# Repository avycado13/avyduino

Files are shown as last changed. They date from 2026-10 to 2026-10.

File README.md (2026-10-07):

# Avyduino

My take on the classic Arduino UNO. Powered by the same chips, but using a USB-C socket.
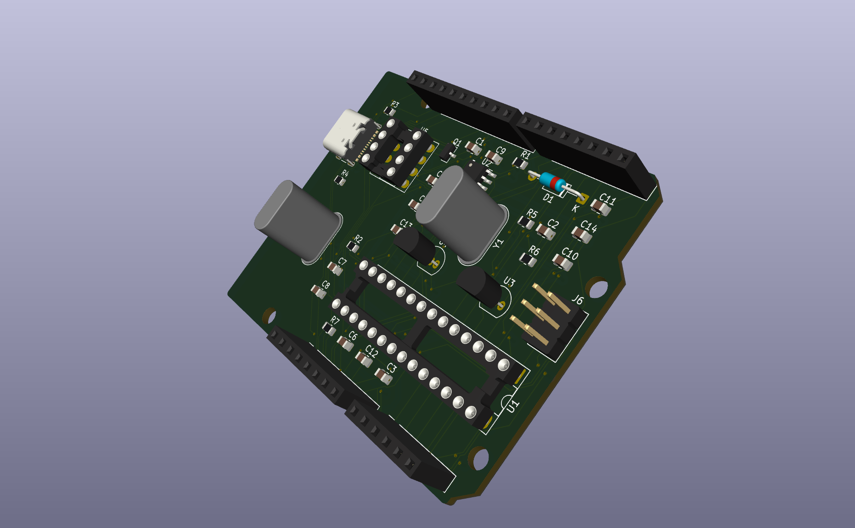
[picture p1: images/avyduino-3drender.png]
3D View

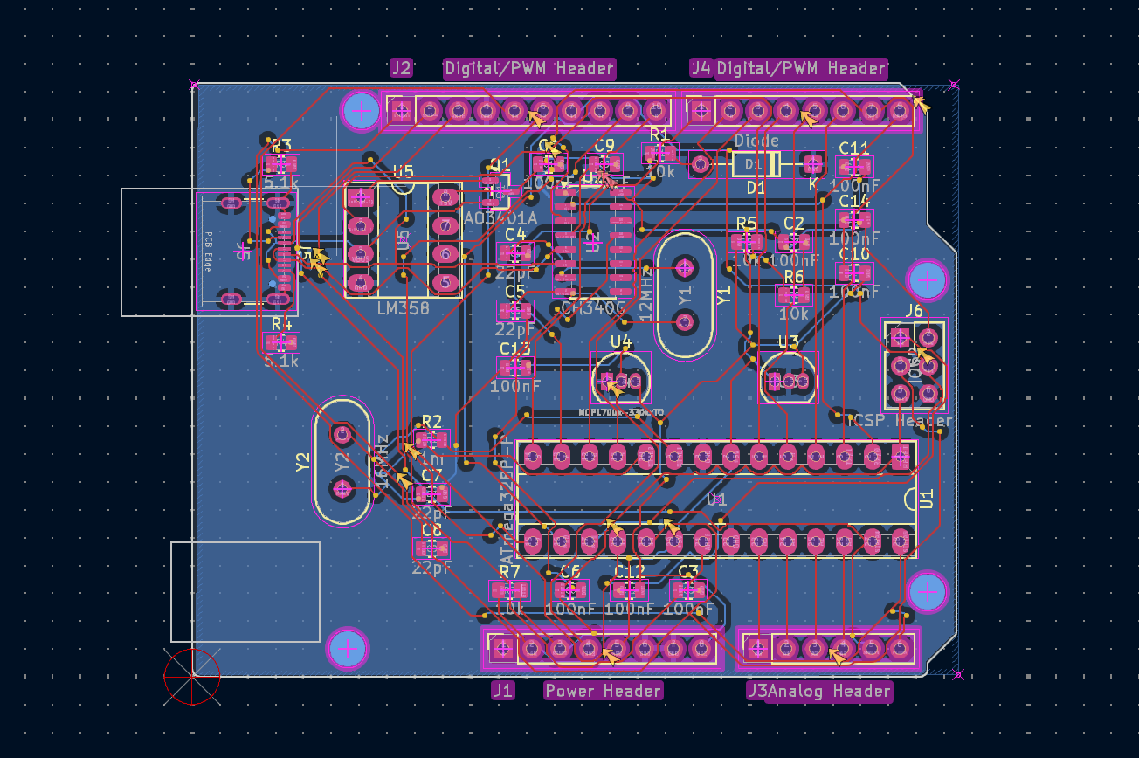
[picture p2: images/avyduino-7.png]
PCB


## Features
- USB-C
- Exact same pinout as classic Arduino UNO
- Power input switching
- Easy to solder components

## BOM
**FORGE REVIEWERS PLEASE ACTUALLY USE MY CSV**
I compiled 2 BOMs. One is from octopart and has parts sourced from multiple separate suppliers. [BOM here](ordering/bom.xlsx) and one entirely from LCSC. [BOM here](ordering/bom_lcsc_only.xlsx)

## Firmware
See [firmware/README.md](firmware/README.md) for the Uno Optiboot first-flash procedure and a USB serial bring-up sketch. The ATmega328P uses the standard Arduino Uno bootloader; the CH340G is a USB-to-UART bridge and does not need custom firmware.

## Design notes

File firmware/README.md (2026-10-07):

# Avyduino firmware

This board uses an **ATmega328P at 16 MHz** (Y2 in the schematic), a CH340G USB-to-UART bridge (its 12 MHz crystal is separate), and a 6-pin ICSP header. It is compatible with the **Arduino Uno** board definition. The bootloader is the official Uno **Optiboot** supplied by the `arduino:avr` core; no custom bootloader is needed. `firmware.ino` is a bring-up sketch: it echoes USB serial input at 115200 baud and toggles D13 every 500 ms. For a visible heartbeat, connect an external LED **with a current-limiting resistor** from D13 to GND; don't assume an onboard D13 LED.

## First-time programming (blank ATmega328P)

1. Install [Arduino CLI](https://arduino.github.io/arduino-cli/latest/installation/) and run `cd firmware && make core` (or install `arduino:avr` using the Arduino IDE Boards Manager).
2. Assemble and power the board. Connect a 5 V-compatible ISP programmer to the **ATmega328P's** 6-pin ICSP header: MISO, MOSI, SCK, RESET, 5V and GND. Check the physical header orientation against the PCB/schematic. Do not drive the target from two power supplies without checking their compatibility.
3. Run `make burn PROGRAMMER=usbasp` from `firmware/` (replace `usbasp` with your programmer's Arduino CLI ID). This writes Uno Optiboot and the Uno fuse settings. **Only do this if the ATmega's 16 MHz crystal and its load capacitors are populated**: the external-clock fuses can make ISP programming appear to stop working if the oscillator is absent. Bootloader burning is not done over the CH340G USB port.

## Upload and test

1. Connect USB-C and find the CH340G serial port using `arduino-cli board list` (e.g. `/dev/ttyUSB0`, `/dev/cu.wchusbserial*`, or `COM3`). On some systems the CH340 driver must be installed separately.
2. From `firmware/`, run `make upload PORT=/dev/ttyUSB0` (substitute your port). This builds for `arduino:avr:uno` and uploads at the Uno's bootloader baud rate. The programmer is **not** needed for this step. Alternatively open `firmware.ino` in Arduino IDE, select **Arduino Uno** and the CH340 serial port, and click Upload.
3. Open a serial monitor at **115200 baud**. Resetting or opening the port should print `Avyduino ready...`; text sent to it is echoed back. D13 changes state twice per second. If a terminal's local echo is enabled, characters may appear twice.

If USB upload fails, verify power, CH340 enumeration, that the bootloader was burned, and that the CH340 TX/RX and DTR-to-RESET connections are working. An ISP can also upload sketches directly, but doing so overwrites the bootloader; burn it again to restore USB uploads.

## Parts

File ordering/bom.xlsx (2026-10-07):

Original Part | Original Manufacturer | Matched Part Number | Part Match | Description | Quantity | Selected Offers | Selected Distributor | Selected Distributor SKU | Selected Offers (Distributor Link) | Stock | Unit Price, $ | Total Quantity | Total Price
CH340G |  |  | Not Found |  | 1
C0805C104K5RACTU |  | C0805C104K5RACTU | Exact | 50V 100nF X7R ±10% 0805 Multilayer Ceramic Capacitors MLCC - SMD/SMT ROHS | 10 | LCSC C75414 (https://octopart.com/opatz8j6/a1) | LCSC | C75414 (https://octopart.com/opatz8j6/a1) | https://octopart.com/opatz8j6/a1 | 4700 | 0.0415 | 10 | 0.415
C0805C220J5GACTU |  | C0805C220J5GACTU | Exact | Ceramic capacitor, 22 pF, 50 V (DC), ±5 %, SMD 0805 (2012), C0G, C0805C220J5GAC7800 | 4 | Newark C0805C220J5GACTU (https://octopart.com/opatz8j6/a1) | Newark | C0805C220J5GACTU (https://octopart.com/opatz8j6/a1) | https://octopart.com/opatz8j6/a1 | 815 | 0.171 | 4 | 0.684
1N4148 |  | 1N4148 | Exact | Rectifier Diode Single 2 EAR99 Diode Rectifier Diode 0.15A 0.004MUS 1V 150C | 1 | Mouser 512-1N4148 (https://octopart.com/opatz8j6/a1) | Mouser | 512-1N4148 (https://octopart.com/opatz8j6/a1) | https://octopart.com/opatz8j6/a1 | 1173802 | 0.1 | 1 | 0.1
SSW-108-01-T-S |  | SSW-108-01-T-S | Exact | PCB Receptacle, Board-to-Board, 2.54 mm, 1 Rows, 8 Contacts, Through Hole Mount, SSW Series | 1 | Mouser 200-SSW10801TS (https://octopart.com/opatz8j6/a1) | Mouser | 200-SSW10801TS (https://octopart.com/opatz8j6/a1) | https://octopart.com/opatz8j6/a1 | 1498 | 0.85 | 1 | 0.85
SSW-106-01-T-S |  | SSW-106-01-T-S | Exact | PCB Receptacle, Board-to-Board, 2.54 mm, 1 Rows, 6 Contacts, Through Hole Mount, SSW Series | 1 | Mouser 200-SSW10601TS (https://octopart.com/opatz8j6/a1) | Mouser | 200-SSW10601TS (https://octopart.com/opatz8j6/a1) | https://octopart.com/opatz8j6/a1 | 9012 | 0.58 | 1 | 0.58
SSW-108-01-T-S |  | SSW-108-01-T-S | Exact | PCB Receptacle, Board-to-Board, 2.54 mm, 1 Rows, 8 Contacts, Through Hole Mount, SSW Series | 1 | Mouser 200-SSW10801TS (https://octopart.com/opatz8j6/a1) | Mouser | 200-SSW10801TS (https://octopart.com/opatz8j6/a1) | https://octopart.com/opatz8j6/a1 | 1498 | 0.85 | 1 | 0.85
TSW-103-07-G-D |  | TSW-103-07-G-D | Exact | CONN HEADER VERT 6POS 2.54MM / Connector Header Through Hole 6 position 0.100" (2.54mm) | 1 | Mouser 200-TSW10307GD (https://octopart.com/opatz8j6/a1) | Mouser | 200-TSW10307GD (https://octopart.com/opatz8j6/a1) | https://octopart.com/opatz8j6/a1 | 7100 | 0.43 | 1 | 0.43
AO3401A |  | AO3401A | Exact | Transistor: P-MOSFET; unipolar; -30V; 4, 2A; 1, 4W; 85 mOhm; ; -55+150 st.C; SMD; SOT23 | 1 | LCSC C15127 (https://octopart.com/opatz8j6/a1) | LCSC | C15127 (https://octopart.com/opatz8j6/a1) | https://octopart.com/opatz8j6/a1 | 348335 | 0.1026 | 5 | 0.513
ERJ6ENF1002V |  | ERJ6ENF1002V | Exact | Res Thick Film 0805 10K Ohm 1% 1/8W ±100ppm/°C Molded SMD Punched Carrier T/R | 4 | Mouser 667-ERJ-6ENF1002V (https://octopart.com/opatz8j6/a1) | Mouser | 667-ERJ-6ENF1002V (https://octopart.com/opatz8j6/a1) | https://octopart.com/opatz8j6/a1 | 1016210 | 0.038 | 10 | 0.38
EE-SX953-W 1M |  | AC0805FR-071ML | Exact | SMD Chip Resistor, 1 MOhm, ¡À 1%, 125 mW, 0805 [2012 Metric], Thick Film, General Purpose | 1 | Mouser 603-AC0805FR-071ML (https://octopart.com/opatz8j6/a1) | Mouser | 603-AC0805FR-071ML (https://octopart.com/opatz8j6/a1) | https://octopart.com/opatz8j6/a1 | 10709 | 0.1 | 1 | 0.1
RC0805FR-075K1L |  | RC0805FR-075K1L | Exact | Res Thick Film 0805 5.1K Ohm 1% 0.125W(1/8W) ±100ppm/C Pad SMD T/R | 2 | Newark RC0805FR-075K1L (https://octopart.com/opatz8j6/a1) | Newark | RC0805FR-075K1L (https://octopart.com/opatz8j6/a1) | https://octopart.com/opatz8j6/a1 | 59224 | 0.101 | 2 | 0.202
LM2931AZ-5.0RAG |  | LM2931AZ-5.0RAG | Exact | LM2931 Series 100 mA 5 V Fixed Output Through Hole LDO Voltage Regulator - TO-92 | 1 | Mouser 863-LM2931AZ-5.0RAG (https://octopart.com/opatz8j6/a1) | Mouser | 863-LM2931AZ-5.0RAG (https://octopart.com/opatz8j6/a1) | https://octopart.com/opatz8j6/a1 | 1943 | 0.61 | 1 | 0.61
LM358S-13 |  | LM358S-13 | Exact | DIODES INC. LM358S-13 Operational Amplifier, Dual, 1 MHz, 2 Amplifier, 3V to 32V, SOIC, 8 Pins | 1 | Mouser 621-LM358S-13 (https://octopart.com/opatz8j6/a1) | Mouser | 621-LM358S-13 (https://octopart.com/opatz8j6/a1) | https://octopart.com/opatz8j6/a1 | 5902 | 0.23 | 1 | 0.23
ABLS2-12.000MHZ-D4Y-T |  | ABLS2-12.000MHZ-D4Y-T | Exact | Crystal 12MHz ±30ppm (Tol) ±30ppm (Stability) 18pF FUND 50Ohm 2-Pin HC-49/US SMD T/R | 1 | Newark ABLS2-12.000MHZ-D4Y-T (https://octopart.com/opatz8j6/a1) | Newark | ABLS2-12.000MHZ-D4Y-T (https://octopart.com/opatz8j6/a1) | https://octopart.com/opatz8j6/a1 | 43386 | 0.337 | 1 | 0.337
ABM8G-16.000MHZ-18-D2Y-T |  | ABM8G-16.000MHZ-18-D2Y-T | Exact | Crystal 16MHz ±20ppm (Tol) ±30ppm (Stability) 18pF FUND 80Ohm 4-Pin Ultra Mini-CSMD T/R | 1 | Newark ABM8G-16.000MHZ-18-D2Y-T (https://octopart.com/opatz8j6/a1) | Newark | ABM8G-16.000MHZ-18-D2Y-T (https://octopart.com/opatz8j6/a1) | https://octopart.com/opatz8j6/a1 | 1380 | 0.476 | 1 | 0.476
SSW-110-01-T-S |  | SSW-110-01-T-S | Exact | Samtec 2.54mmpitch10pSingle row female Board to Board, SSWseries, Straight, Through-hole | 1 | Mouser 200-SSW11001TS (https://octopart.com/opatz8j6/a1) | Mouser | 200-SSW11001TS (https://octopart.com/opatz8j6/a1) | https://octopart.com/opatz8j6/a1 | 6680 | 1.13 | 1 | 1.13
ATMEGA328P-PU |  | ATMEGA328P-PU | Exact | Microchip - ATMEGA328P-PU - Microcontroller Mcu, 8 Bit, Atmega, 20MHZ, DIP-28 | 1 | LCSC C33901 (https://octopart.com/opatz8j6/a1) | LCSC | C33901 (https://octopart.com/opatz8j6/a1) | https://octopart.com/opatz8j6/a1 | 703 | 2.62 | 1 | 2.62
SS-52400-002 |  | SS-52400-002 | Exact | Conn USB Type C RCP 14 POS 0.4mm/0.8mm Solder RA Thru-Hole 14 Terminal 1 Port T/R | 1 | LCSC C3197989 (https://octopart.com/opatz8j6/a1) | LCSC | C3197989 (https://octopart.com/opatz8j6/a1) | https://octopart.com/opatz8j6/a1 | 126 | 4.74 | 1 | 4.74

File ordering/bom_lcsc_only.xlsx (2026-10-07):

bom.xlsx |  |  |  |  |  |  |  |  |  | LCSC BOM Quotation
 |  |  |  |  |  |  |  |  |  | BOM Date Created：07/10/26 10:29:34 |  |  |  | BOM Export Date: 07/10/26 10:30:51 |  |  |  | The matching result is a real-time query result, availability and prices may fluctuate. Backorder items are estimated prices for your reference, please submit "Create Quote" to get the real price. All information is provided "as is" and is subject to change without notice. Any use made of the information provided is without recourse to LCSC and at the user's risk.
 |  |  |  |  |  |  |  |  |  | EST TOTAL :$17.35 |  |  |  | Website：https://www.lcsc.com/bom | https://www.lcsc.com/bom | https://www.lcsc.com/bom | https://www.lcsc.com/bom
Uploaded data |  |  |  |  |  |  |  |  |  | LCSC Matching Results
LCSC# | Mfr. | Mrf# | Description | Package | Value | Customer Part Number | Quantity | Target Price(USD) | Target Lead Time(Business Days) | Mrf# | Mfr. | Order Qty. | Unit Price(USD) | Ext.Price(USD) | LCSC# | Package | Min | Mult | SPQ | Availability | Stock Status | Customer Notes | Description | Matched status | Product Link
 |  |  |  |  |  |  | 1 |  |  | -(The data has been deleted.) | - | - | - | - | - | - | - | - | - | - | - | - | - | - | https://uat.lcsc.com/product-detail/schottky-barrier-diodes-sbd_lge-10mq040n_C688893.html
 |  | C0805C104K5RACTU | 50V 100nF X7R ±10% 0805 Multilayer Ceramic Capacitors MLCC - SMD/SMT ROHS |  |  | - | 10 |  |  | C0805C104K5RACTU | KEMET | 10 | 0.0310 | 0.31 | C3018562 | - | 10 | 10 | 4000 | 4270 | In Stock |  | 100nF ±10% 50V Ceramic Capacitor X7R 0805 | Exact Matches
 |  | C0805C220J5GACTU | Ceramic capacitor, 22 pF, 50 V (DC), ±5 %, SMD 0805 (2012), C0G, C0805C220J5GAC7800 |  |  | - | 4 |  |  | C0805C220J5GACTU | KEMET | 50 | 0.0135 | 0.68 | C22401914 | - | 50 | 50 | 4000 | 2400 | In Stock |  | 22pF C0G ±5% 50V 0805 Ceramic Capacitors RoHS | Exact Matches
 |  | 1N4148 | Rectifier Diode Single 2 EAR99 Diode Rectifier Diode 0.15A 0.004MUS 1V 150C |  |  | - | 1 |  |  | 1N4148 | Changzhou Starsea Elec | 50 | 0.0084 | 0.42 | C85057 | - | 50 | 50 | 5000 | 29200 | In Stock |  | Diode 100V 150mA Through Hole DO-35 | Exact Matches
 |  | SSW-108-01-T-S | PCB Receptacle, Board-to-Board, 2.54 mm, 1 Rows, 8 Contacts, Through Hole Mount, SSW Series |  |  | - | 1 |  |  | SSW-108-01-T-S | Samtec | 1 | 0.8600 | 0.86 | C6236331 | Through Hole,P=2.54mm | 1 | 1 | 7 | 3 | In Stock |  | Female Header 8 Position 2.54mm Pitch Single Row Through Hole -55℃~+105℃ | Exact Matches | https://www.lcsc.com/product-detail/C6236331.html
 |  | SSW-106-01-T-S | PCB Receptacle, Board-to-Board, 2.54 mm, 1 Rows, 6 Contacts, Through Hole Mount, SSW Series |  |  | - | 1 |  |  | SSW-106-01-T-S | Samtec | 1 | 1.2470 | 1.25 | C3323824 | - | 1 | 1 | 7 | 0 | Backordered |  | Female Header 6 Position 2.54mm Pitch Single Row Through Hole -55℃~+105℃ | Exact Matches
 |  | SSW-108-01-T-S | PCB Receptacle, Board-to-Board, 2.54 mm, 1 Rows, 8 Contacts, Through Hole Mount, SSW Series |  |  | - | 1 |  |  | SSW-108-01-T-S | Samtec | 1 | 0.8600 | 0.86 | C6236331 | Through Hole,P=2.54mm | 1 | 1 | 7 | 3 | In Stock |  | Female Header 8 Position 2.54mm Pitch Single Row Through Hole -55℃~+105℃ | Exact Matches | https://www.lcsc.com/product-detail/C6236331.html
 |  | TSW-103-07-G-D | CONN HEADER VERT 6POS 2.54MM / Connector Header Through Hole 6 position 0.100" (2.54mm) |  |  | - | 1 |  |  | TSW-103-07-G-D | Samtec | 1 | 0.6589 | 0.66 | C6339671 | - | 1 | 1 | 2000 | 34 | In Stock |  | Pin Header 6 Position 2.54mm Pitch Dual Row Through Hole -55℃~+125℃ | Exact Matches
 |  | AO3401A | Transistor: P-MOSFET; unipolar; -30V; 4, 2A; 1, 4W; 85 mOhm; ; -55+150 st.C; SMD; SOT23 |  |  | - | 1 |  |  | AO3401A | TECH PUBLIC | 20 | 0.0248 | 0.50 | C5122001 | - | 20 | 20 | 3000 | 50240 | In Stock |  | 30V 4.2A 1.2W Surface Mount SOT-23 | Exact Matches
 |  | ERJ6ENF1002V | Res Thick Film 0805 10K Ohm 1% 1/8W ±100ppm/°C Molded SMD Punched Carrier T/R |  |  | - | 4 |  |  | ERJ6ENF1002V | PANASONIC | 50 | 0.0052 | 0.26 | C169253 | - | 50 | 50 | 5000 | 36750 | In Stock |  | 125mW 10kΩ Thick Film Resistor ±100ppm/℃ ±1% 0805 Chip Resistor - Surface Mount RoHS | Exact Matches
 |  | AC0805FR-071ML | SMD Chip Resistor, 1 MOhm, ¡À 1%, 125 mW, 0805 [2012 Metric], Thick Film, General Purpose |  |  | - | 1 |  |  | AC0805FR-071ML | YAGEO | 100 | 0.0032 | 0.32 | C228604 | - | 100 | 100 | 5000 | 247300 | In Stock |  | 125mW 1MΩ 150V Thick Film Resistor ±100ppm/℃ ±1% 0805 Chip Resistor - Surface Mount RoHS | Exact Matches
 |  | RC0805FR-075K1L | Res Thick Film 0805 5.1K Ohm 1% 0.125W(1/8W) ±100ppm/C Pad SMD T/R |  |  | - | 2 |  |  | RC0805FR-075K1L | YAGEO | 100 | 0.0016 | 0.16 | C84375 | - | 100 | 100 | 5000 | 790200 | In Stock |  | 5.1kΩ 125mW 150V Thick Film Resistor ±100ppm/℃ ±1% 0805 Chip Resistor - Surface Mount RoHS | Exact Matches
 |  | LM2931AZ-5.0RAG | LM2931 Series 100 mA 5 V Fixed Output Through Hole LDO Voltage Regulator - TO-92 |  |  | - | 1 |  |  | LM2931AZ-5.0RAG | onsemi | 1 | 0.3193 | 0.32 | C415867 | - | 1 | 1 | 2000 | 0 | Backordered |  | Linear Voltage Regulator IC Positive Fixed 1 Output 100mA TO-92 | Exact Matches
 |  | LM358S-13 | DIODES INC. LM358S-13 Operational Amplifier, Dual, 1 MHz, 2 Amplifier, 3V to 32V, SOIC, 8 Pins |  |  | - | 1 |  |  | LM358S-13 | DIODES | 5 | 0.1518 | 0.76 | C2058968 | SOP-8 | 5 | 5 | 2500 | 850 | In Stock |  | 60mA 2 2mV 85dB 45nA 1mA 1MHz SOP-8 Instrumentation, Op Amps, Buffer Amps RoHS | Exact Matches | https://www.lcsc.com/product-detail/C2058968.html
 |  | ABLS2-12.000MHZ-D4Y-T | Crystal 12MHz ±30ppm (Tol) ±30ppm (Stability) 18pF FUND 50Ohm 2-Pin HC-49/US SMD T/R |  |  | - | 1 |  |  | ABLS2-12.000MHZ-D4Y-T | ABRACON | 5 | 0.2564 | 1.28 | C1985239 | - | 5 | 5 | 1000 | 1260 | In Stock |  | Crystal 12MHz ±30ppm 18pF 50Ω HC-49S-SMD | Exact Matches
 |  | ABM8G-16.000MHZ-18-D2Y-T | Crystal 16MHz ±20ppm (Tol) ±30ppm (Stability) 18pF FUND 80Ohm 4-Pin Ultra Mini-CSMD T/R |  |  | - | 1 |  |  | ABM8G-16.000MHZ-18-D2Y-T | ABRACON | 1 | 0.3804 | 0.38 | C1985423 | - | 1 | 1 | 1000 | 710 | In Stock |  | Crystal 16MHz ±20ppm 18pF 80Ω SMD3225-4P | Exact Matches
 |  | SSW-110-01-T-S | Samtec 2.54mmpitch10pSingle row female Board to Board, SSWseries, Straight, Through-hole |  |  | - | 1 |  |  | SSW-110-01-T-S | Samtec | 1 | 1.3004 | 1.30 | C6825788 | Through Hole,P=2.54mm | 1 | 1 | 7 | 9 | In Stock |  | Female Header 10 Position 2.54mm Pitch Single Row Through Hole -55℃~+105℃ | Exact Matches | https://www.lcsc.com/product-detail/C6825788.html
 |  | ATMEGA328P-PU | Microchip - ATMEGA328P-PU - Microcontroller Mcu, 8 Bit, Atmega, 20MHZ, DIP-28 |  |  | - | 1 |  |  | ATMEGA328P-PU | MICROCHIP | 1 | 2.3274 | 2.33 | C33901 | - | 1 | 1 | 14 | 691 | In Stock |  | AVR 8 Bit 20MHz DIP-28-300mil Microcontrollers RoHS | Exact Matches
 |  | SS-52400-002 | Conn USB Type C RCP 14 POS 0.4mm/0.8mm Solder RA Thru-Hole 14 Terminal 1 Port T/R |  |  | - | 1 |  |  | SS-52400-002 | Bel Fuse | 1 | 4.1276 | 4.13 | C3197989 | - | 1 | 1 | 700 | 124 | In Stock |  | USB 3.2 1 24P -40℃~+105℃ Right Angle Through Hole USB, DVI, HDMI Connector Assemblies RoHS | Exact Matches
 |  |  |  |  |  |  | 1 |  |  | CH340G | WCH | 1 | 0.5715 | 0.57 | C14267 | SOP-16 | 1 | 1 | 50 | 27331 | In Stock |  | USB to UART 2Mbps USB 2.0 SOP-16 Interface Controllers | Exact Matches | https://www.lcsc.com/product-detail/C14267.html

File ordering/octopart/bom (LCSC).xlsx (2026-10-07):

Designator | Footprint | Quantity | Value | LCSC Part # | Original Part | Original Manufacturer | Matched Part Number | Part Match | Description | Quantity | Selected Offers | Selected Distributor | Selected Distributor SKU | Selected Offers (Distributor Link) | Stock | Unit Price, $ | Total Quantity | Total Price
C1, C2, C3, C6, C9, C10, C11, C12, C13, C14 | 0805 | 10 | 100nF | C0805C104K5RACTU | C0805C104K5RACTU |  | C0805C104K5RACTU | Exact | 50V 100nF X7R ±10% 0805 Multilayer Ceramic Capacitors MLCC - SMD/SMT ROHS | 10 | LCSC C75414 (https://octopart.com/opatz8j6/a1) | LCSC | C75414 (https://octopart.com/opatz8j6/a1) | https://octopart.com/opatz8j6/a1 | 4700 | 0.0415 | 10 | 0.415
Q1 | SOT-23 | 1 | AO3401A | AO3401A | AO3401A |  | AO3401A | Exact | Transistor: P-MOSFET; unipolar; -30V; 4, 2A; 1, 4W; 85 mOhm; ; -55+150 st.C; SMD; SOT23 | 1 | LCSC C15127 (https://octopart.com/opatz8j6/a1) | LCSC | C15127 (https://octopart.com/opatz8j6/a1) | https://octopart.com/opatz8j6/a1 | 348335 | 0.1026 | 5 | 0.513
U1 | DIP-28_W7.62mm_Socket_LongPads | 1 | ATmega328P-P | ATMEGA328P-PU | ATMEGA328P-PU |  | ATMEGA328P-PU | Exact | Microchip - ATMEGA328P-PU - Microcontroller Mcu, 8 Bit, Atmega, 20MHZ, DIP-28 | 1 | LCSC C33901 (https://octopart.com/opatz8j6/a1) | LCSC | C33901 (https://octopart.com/opatz8j6/a1) | https://octopart.com/opatz8j6/a1 | 703 | 2.62 | 1 | 2.62
J5 | USB_C_Receptacle_GCT_USB4105-xx-A_16P_TopMnt_Horizontal | 1 | USB_C_Receptacle_USB2.0_14P | SS-52400-002 | SS-52400-002 |  | SS-52400-002 | Exact | Conn USB Type C RCP 14 POS 0.4mm/0.8mm Solder RA Thru-Hole 14 Terminal 1 Port T/R | 1 | LCSC C3197989 (https://octopart.com/opatz8j6/a1) | LCSC | C3197989 (https://octopart.com/opatz8j6/a1) | https://octopart.com/opatz8j6/a1 | 126 | 4.74 | 1 | 4.74

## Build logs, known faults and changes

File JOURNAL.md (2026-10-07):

---
title: "avyduino"
github: "avycado13/avyduino"
description: "an arduino but my way"
created_at: "2026-10-04"
---

# Oct 5: Started Project and Made Schematic
I had the idea to make my own Arduino UNO based on the same chips but hand solderable and cooler!
I used an ATmega328p for the microcontroller and a CH340G to convert USB to UART. Making the power systems was a bit hard because I had to replicate Arduino's system of using an Op-amp and a MOSFET to decide between using the VBUS from USB and the VIN from the pins. I used KiCad's Arduino UNO template which already had the pin headers set up in the right order. For USB, I went with a USB-C port because its more modern and easier to find a cable for then that obscure USB-B that Arduino's usually come with. A big help in this was [Kai's build your own devboard guide](https://kaipereira.com/journal/build-a-devboard) and online Arduino schematics.

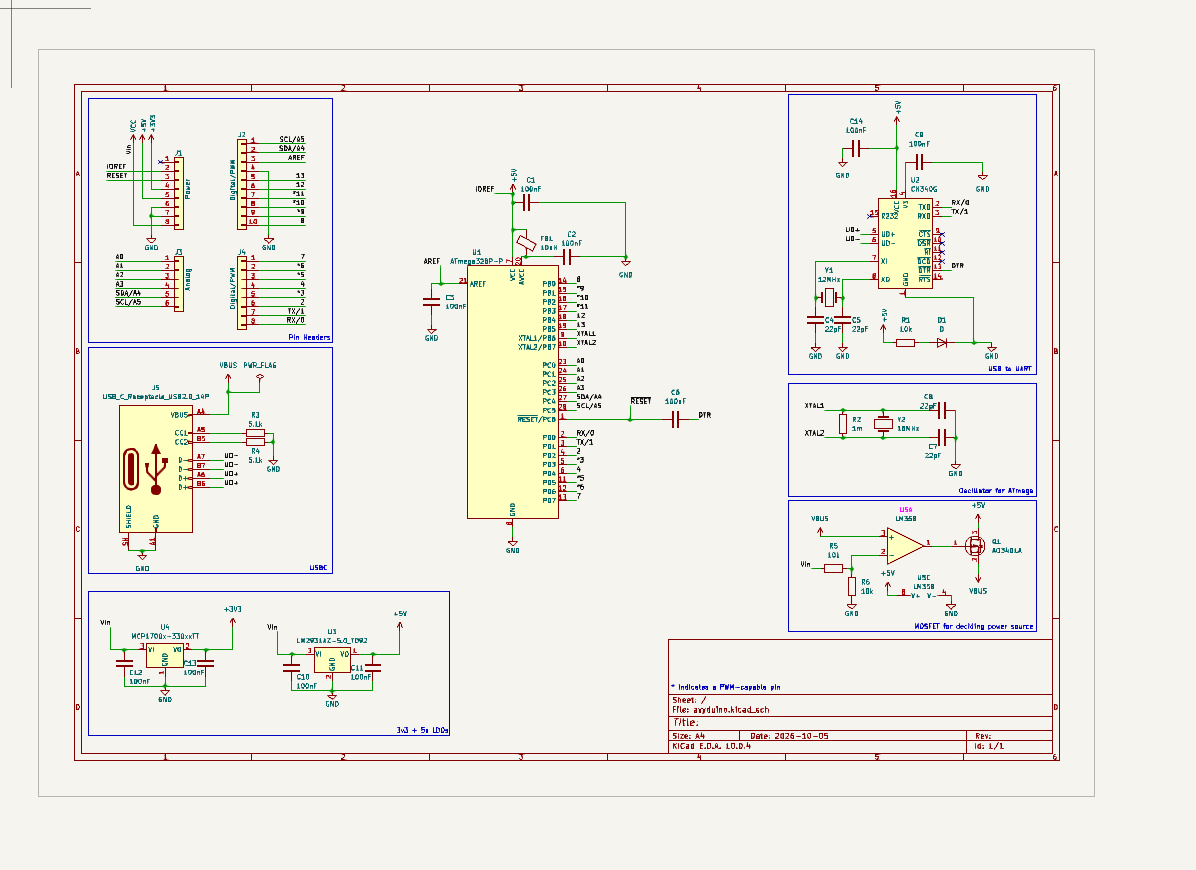
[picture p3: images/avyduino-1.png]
Final Schematic

**Total Time Spent: 3 Hours**

# Oct 5: Laid out PCB
I laid out my PCB. The KiCad template already had the shape I needed in it so I didn't need to try drawing it. I tried laying things out to be close to where they need to connect, especially my decoupling capacitors because on past projects I screwed it up and forgot that they should go closer to the place they are connected to.

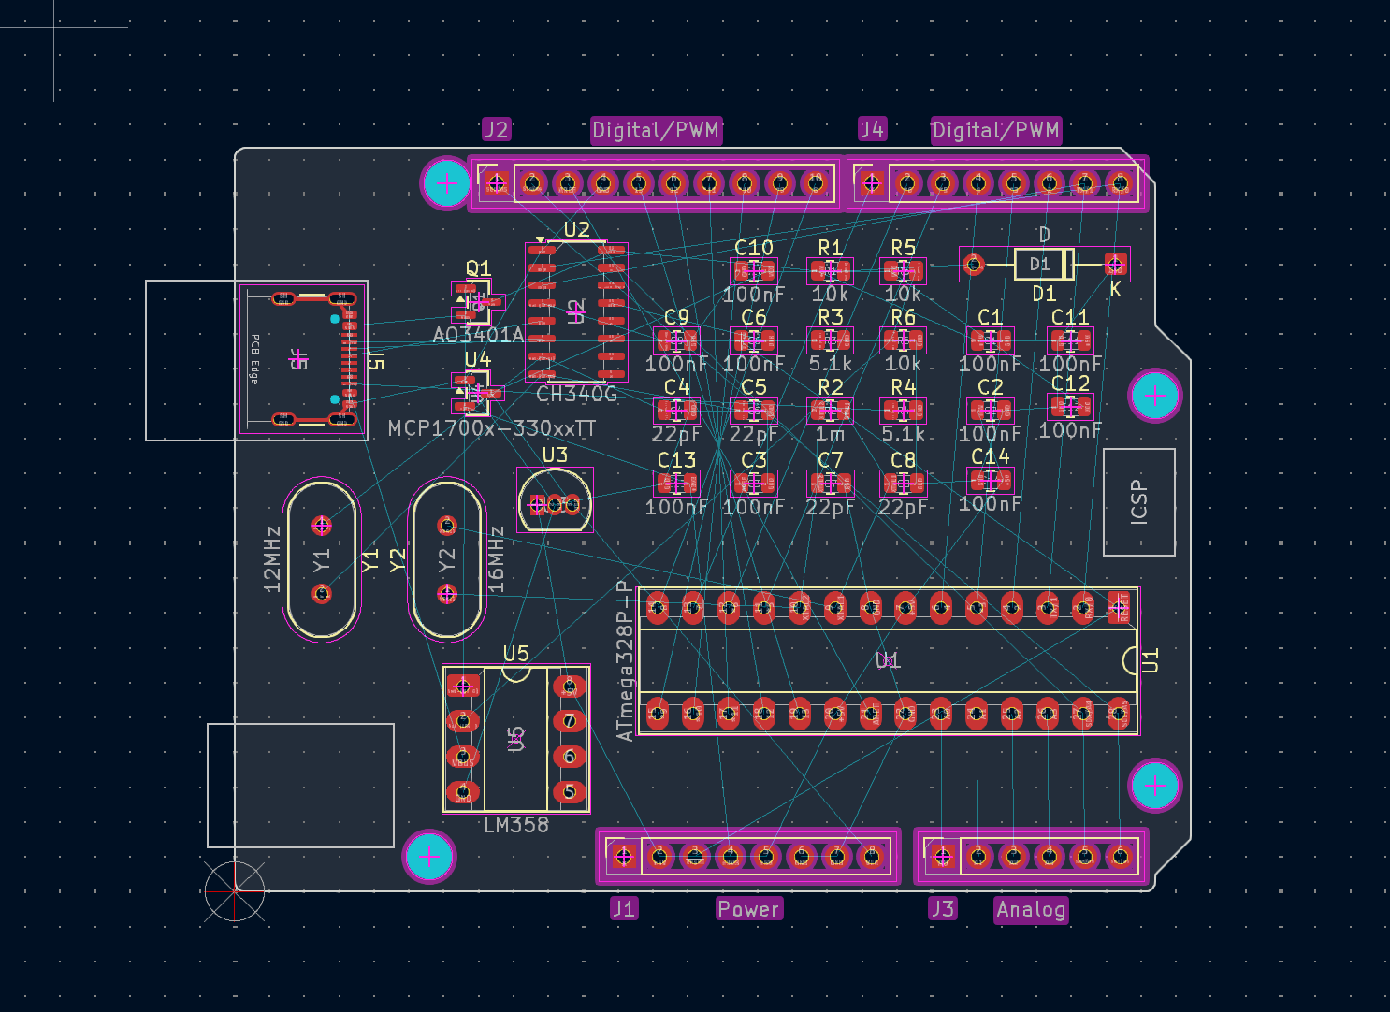
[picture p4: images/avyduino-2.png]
Completed Layout

**Total Time Spent: 2 Hours**

# Oct 5: Routed PCB
I routed my PCB through the night with one GND plane and one plane for VCC. I routed it with standard size traces and kinda went overboard on the vias.

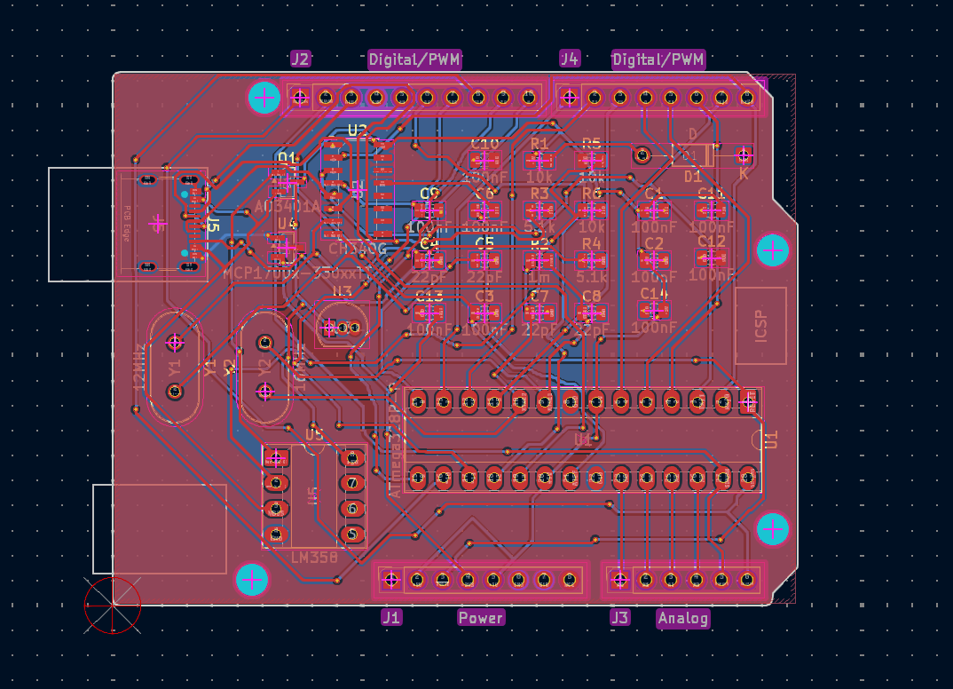
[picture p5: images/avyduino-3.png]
Completed PCB with Layout

**Total Time Spent: 1.5 Hour**

# Oct 6: Add ICSP Header
I forgot to add an ICSP header for flashing it initially. So I added one to my schematic. I was a bit confused by the fact that it uses an SPI bus that also doubles as PWM pins but now it makes sense, but its still weird that it uses pins that could be occupied. it apparently just pulses really fast during flashing.

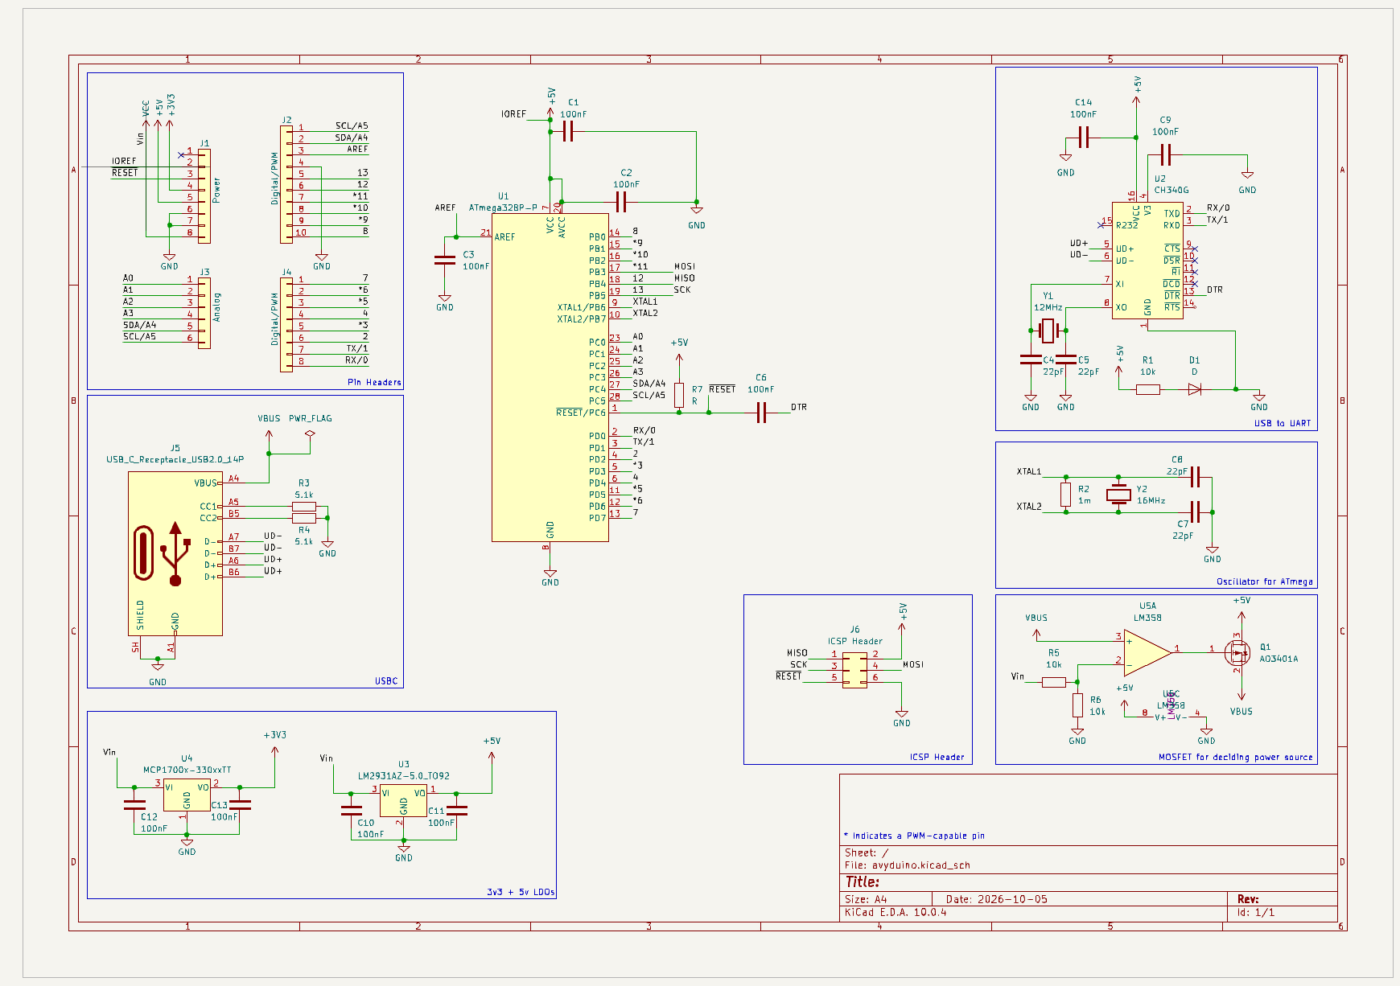
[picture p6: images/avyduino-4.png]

**Total Time Spent: 1 Hour**

# Oct 6: Add ICSP Header to PCB
I added the ICSP header to the PCB and routed it. The DRC and ERC both pass, so I think I am good. Next, I just need to source the parts and write my README.

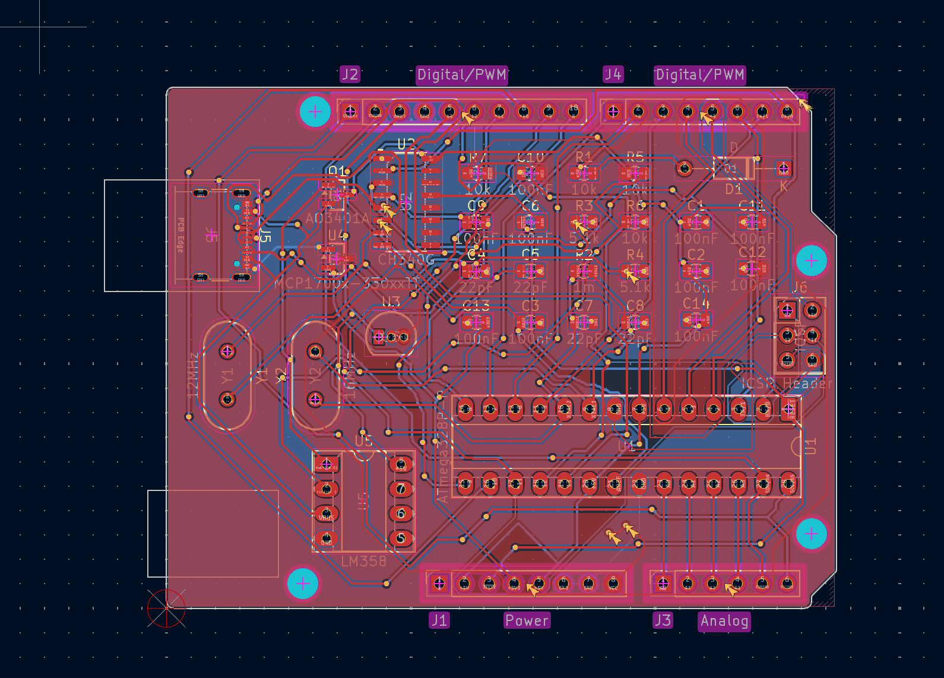
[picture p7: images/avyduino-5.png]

**Total Time Spent: 0.5 Hour**

# Oct 6: Redo Layout of PCB
I had started to put part numbers on things when I realized that my layout wasn't that great and I could make it better and I also wanted to switch the footprint of some things to be easier to solder. I redid the layout and updated some names and footprints.

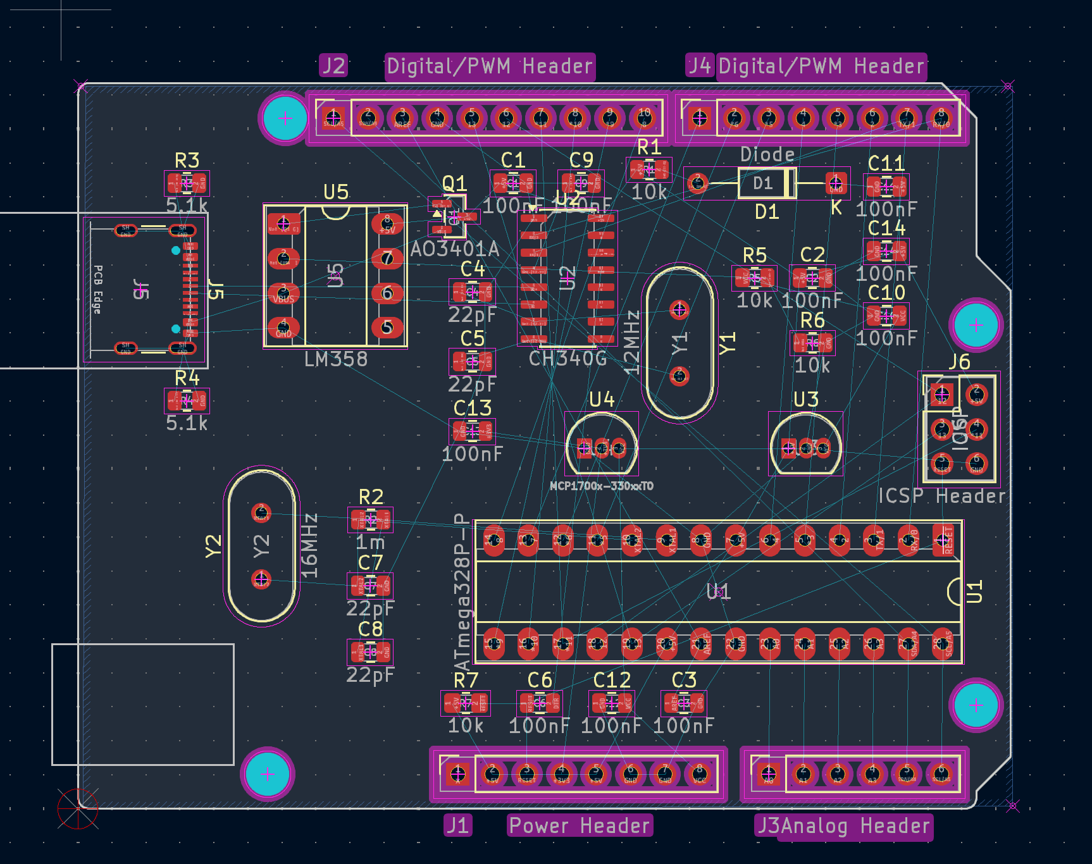
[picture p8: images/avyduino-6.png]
New PCB Layout

**Total Time Spent: 1 Hour**

# Oct 6: Route PCB
I rerouted the PCB with the new layout. For this one, I got rid of the Front VCC plane and only used a ground plane on the back layer. I forgot to commit this journal log because I had to do something so ya.
Routed PCB with new layout
**Total Time Spent: 1 Hour**

# Oct 6: Make BOMs
I made the BOMs in octopart and exported the production files. I also made one BOM that uses only LCSC parts.

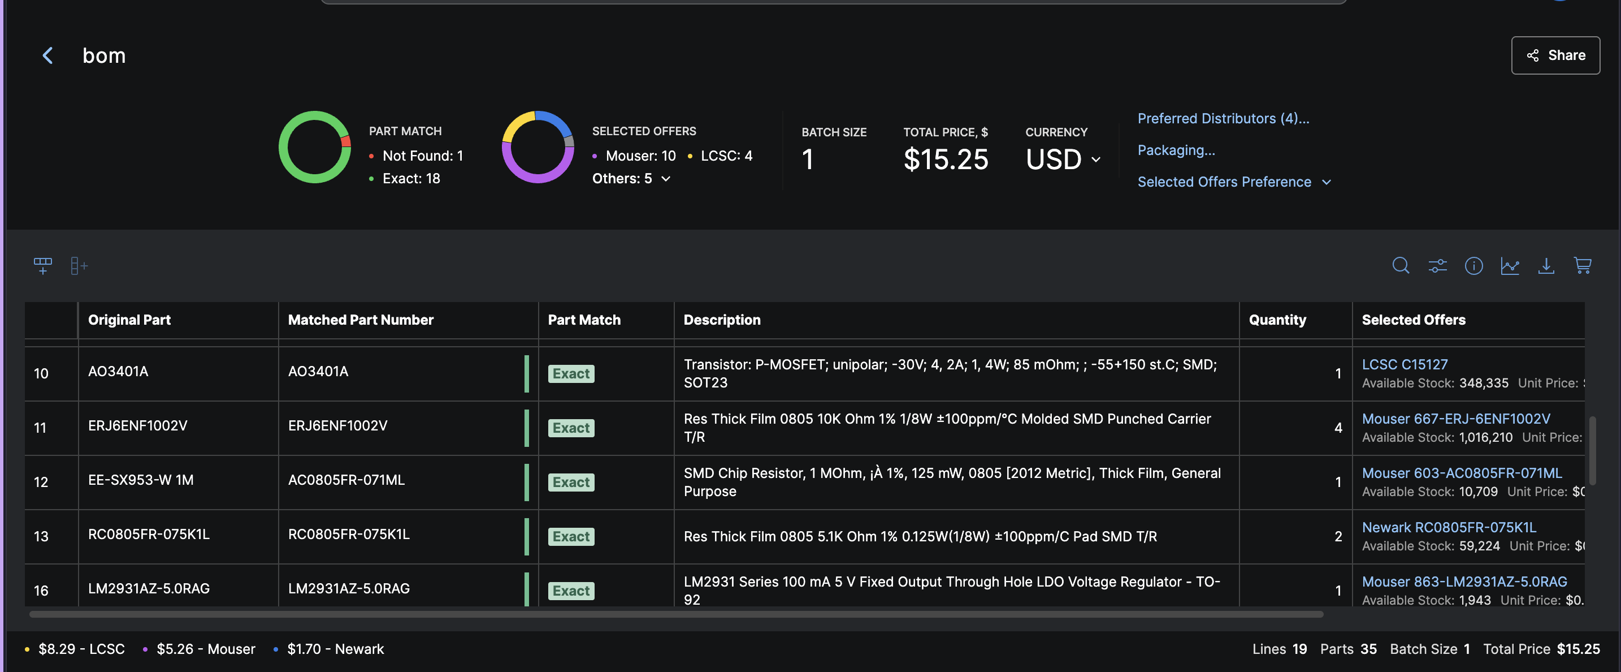
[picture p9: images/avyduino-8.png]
Octopart

**Total Time Spent: 1.5 Hour**

# Oct 7: Add firmware
I added a basic sketch to flash an LED on pin D13 every 0.5 seconds and a Makefile to flash the arduino. there is one command to burn it to the bootloader initially and one for normal flashing. Both just use arduino-cli, so it should work in Arduino IDE. I don't know what image to put, so I am putting the KiCad 3d render.

3D View
**Total Time Spent: 1.5 Hour**

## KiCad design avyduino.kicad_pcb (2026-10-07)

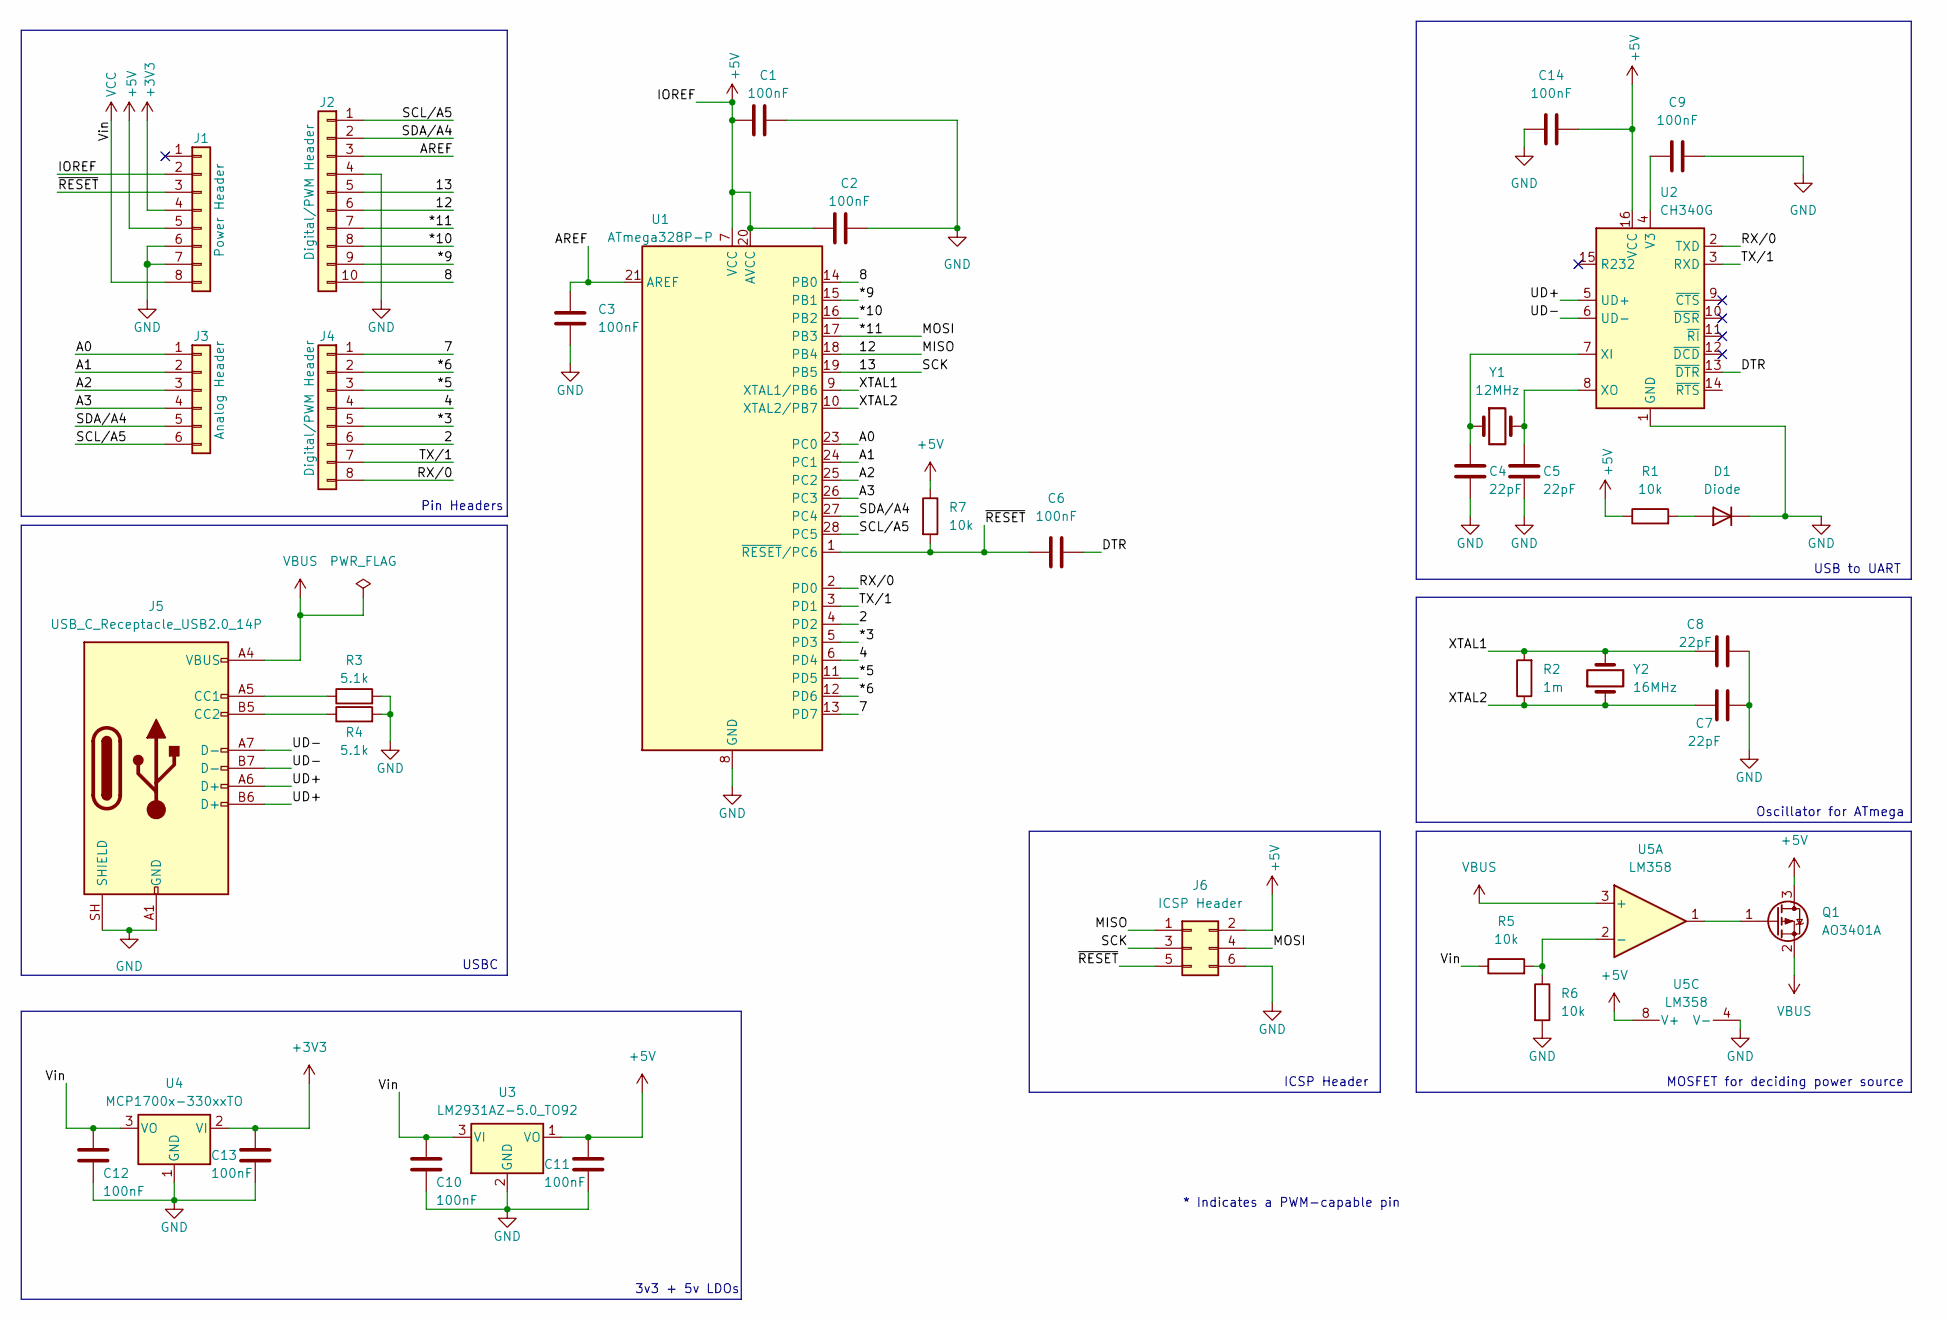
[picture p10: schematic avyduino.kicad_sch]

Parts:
C1, C2, C3, C6, C9, C10, C11, C12, C13, C14: 100nF; C_0805_2012Metric; MPN C0805C104K5RACTU
C4, C5, C7, C8: 22pF; C_0805_2012Metric; MPN C0805C220J5GACTU
D1: Diode; D_DO-35_SOD27_P10.16mm_Horizontal; MPN 1N4148
J1: Power Header; PinSocket_1x08_P2.54mm_Vertical; MPN SSW-108-01-T-S
J2: Digital/PWM Header; PinSocket_1x10_P2.54mm_Vertical; MPN SSW-110-01-T-S
J3: Analog Header; PinSocket_1x06_P2.54mm_Vertical; MPN SSW-106-01-T-S
J4: Digital/PWM Header; PinSocket_1x08_P2.54mm_Vertical; MPN SSW-108-01-T-S
J5: USB_C_Receptacle_USB2.0_14P; USB_C_Receptacle_GCT_USB4105-xx-A_16P_TopMnt_Horizontal; MPN SS-52400-002
J6: ICSP Header; PinHeader_2x03_P2.54mm_Vertical; MPN TSW-103-07-G-D
Q1: AO3401A; SOT-23; MPN AO3401A
R1, R5, R6: 10k; R_0805_2012Metric; MPN ERJ6ENF1002V
R2: 1m; R_0805_2012Metric; MPN AC0805FR-071ML
R3, R4: 5.1k; R_0805_2012Metric; MPN RC0805FR-075K1L
R7: 10k; R_0805_2012Metric_Pad1.20x1.40mm_HandSolder; MPN ERJ6ENF1002V
U1: ATmega328P-P; DIP-28_W7.62mm_Socket_LongPads; MPN ATMEGA328P-PU
U2: CH340G; SOIC-16_3.9x9.9mm_P1.27mm; MPN CH340G
U3: LM2931AZ-5.0_TO92; TO-92_Inline; MPN LM2931AZ-5.0RAG
U4: MCP1700x-330xxTO; TO-92_Inline; MPN MCP1700x-33002E/TO
U5: LM358; DIP-8_W7.62mm_Socket_LongPads; MPN LM358S-13
Y1: 12MHz; Crystal_HC49-U_Vertical; MPN ABLS2-12.000MHZ-D4Y-T
Y2: 16MHz; Crystal_HC49-U_Vertical; MPN ABM8G-16.000MHZ-18-D2Y-T

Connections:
+3V3: C13.2, J1.4, U4.2 (VI)
+5V: C1.1, C2.1, C11.2, C14.2, J1.2, J1.5, J6.2, Q1.3 (D), R1.1, R7.1, U1.7 (VCC), U1.20 (AVCC), U2.16 (VCC), U3.1 (VO), U5.8 (V+)
/2: J4.6, U1.4 (PD2)
/4: J4.4, U1.6 (PD4)
/7: J4.1, U1.13 (PD7)
/8: J2.10, U1.14 (PB0)
/12: J2.6, J6.1, U1.18 (PB4)
/13: J2.5, J6.3, U1.19 (PB5)
/*3: J4.5, U1.5 (PD3)
/*5: J4.3, U1.11 (PD5)
/*6: J4.2, U1.12 (PD6)
/*9: J2.9, U1.15 (PB1)
/*10: J2.8, U1.16 (PB2)
/*11: J2.7, J6.4, U1.17 (PB3)
/A0: J3.1, U1.23 (PC0)
/A1: J3.2, U1.24 (PC1)
/A2: J3.3, U1.25 (PC2)
/A3: J3.4, U1.26 (PC3)
/AREF: C3.1, J2.3, U1.21 (AREF)
/DTR: C6.2, U2.13 (~DTR)
/RX/0: J4.8, U1.2 (PD0), U2.2 (TXD)
/SCL/A5: J2.1, J3.6, U1.28 (PC5)
/SDA/A4: J2.2, J3.5, U1.27 (PC4)
/TX/1: J4.7, U1.3 (PD1), U2.3 (RXD)
/UD+: J5.A6 (D+), J5.B6 (D+), U2.5 (UD+)
/UD-: J5.A7 (D-), J5.B7 (D-), U2.6 (UD-)
/XTAL1: C8.1, R2.2, U1.9 (XTAL1/PB6), Y2.2
/XTAL2: C7.1, R2.1, U1.10 (XTAL2/PB7), Y2.1
/~RESET: C6.1, J1.3, J6.5, R7.2, U1.1 (~RESET/PC6)
GND: C1.2, C2.2, C3.2, C4.2, C5.2, C7.2, C8.2, C9.2, C10.1, C11.1, C12.1, C13.1, C14.1, D1.1 (K), J1.6, J1.7, J2.4, J5.A1 (GND), J5.A12 (GND), J5.B1 (GND), J5.B12 (GND), J5.SH (SHIELD), J6.6, R3.2, R4.2, R6.2, U1.8 (GND), U1.22 (GND), U2.1 (GND), U3.2 (GND), U4.1 (GND), U5.4 (V-)
unnamed: D1.2 (A), R1.2
unnamed: J5.A5 (CC1), R3.1
unnamed: J5.B5 (CC2), R4.1
unnamed: Q1.1 (G), U5.1
unnamed: C9.1, U2.4 (V3)
unnamed: C4.1, U2.7 (XI), Y1.1
unnamed: C5.1, U2.8 (XO), Y1.2
unnamed: R5.2, R6.1, U5.2 (-)
VBUS: J5.A4 (VBUS), J5.A9 (VBUS), J5.B4 (VBUS), J5.B9 (VBUS), Q1.2 (S), U5.3 (+)
VCC: C10.2, C12.2, J1.8, R5.1, U3.3 (VI), U4.3 (VO)

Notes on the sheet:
3v3 + 5v LDOs
ICSP Header
USB to UART
Pin Headers
MOSFET for deciding power source
* Indicates a PWM-capable pin
Oscillator for ATmega
USBC

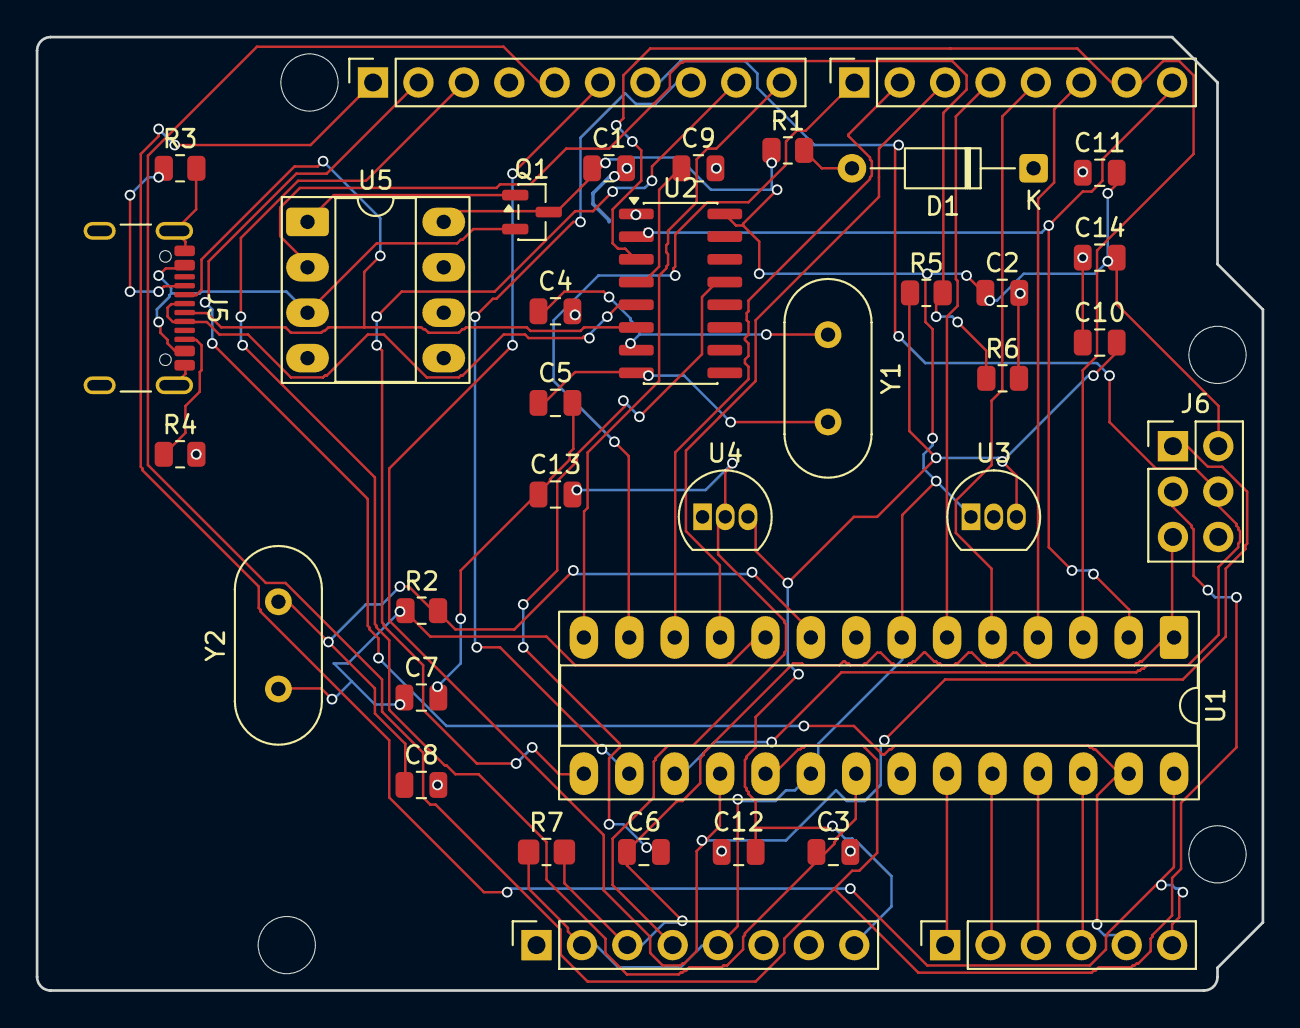
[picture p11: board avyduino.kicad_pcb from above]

Board: 2 copper layers, 68.6 x 53.3 mm, 40 parts (0 on the bottom side), 40 nets.

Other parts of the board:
MH1, MH2, MH3, MH4: MountingHole_3.2mm

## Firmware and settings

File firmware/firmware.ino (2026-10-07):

// Avyduino bring-up sketch for the ATmega328P (Arduino Uno pin mapping).
// The CH340G provides the USB serial port; this chip does not run this sketch.
// Connect an external LED + resistor to D13 if you want to see the heartbeat.

constexpr unsigned long kBaudRate = 115200;
constexpr unsigned long kHeartbeatIntervalMs = 500;

unsigned long lastHeartbeatMs = 0;
bool heartbeatHigh = false;

void setup() {
  pinMode(LED_BUILTIN, OUTPUT);  // D13 / PB5 / SCK
  Serial.begin(kBaudRate);
  Serial.println(F("Avyduino ready. Type to echo; D13 toggles every 500 ms."));
}

void loop() {
  const unsigned long now = millis();
  if (now - lastHeartbeatMs >= kHeartbeatIntervalMs) {
    lastHeartbeatMs = now;
    heartbeatHigh = !heartbeatHigh;
    digitalWrite(LED_BUILTIN, heartbeatHigh ? HIGH : LOW);
  }

  // Echo bytes verbatim so a serial terminal can test RX and TX together.
  while (Serial.available() > 0) {
    Serial.write(Serial.read());
  }
}

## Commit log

2026-10-06 make schematic
    [avyduino.kicad_pcb, avyduino.kicad_sch]
2026-10-06 do layout
    [avyduino.kicad_pcb, avyduino.kicad_sch]
2026-10-06 route the pcb. will add some cool silkscreen
    [avyduino.kicad_pcb]
2026-10-06 added icsp header
    [avyduino.kicad_sch]
2026-10-06 routed ICSP header
    [avyduino.kicad_pcb, avyduino.kicad_sch]
2026-10-07 redo layout of pcb
    [avyduino.kicad_pcb, avyduino.kicad_sch, bom.csv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]
2026-10-07 route pcb and make BOMs
    [avyduino.kicad_pcb, avyduino.kicad_sch, bom (LCSC).xlsx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]
2026-10-13 redo layout and add reset button
